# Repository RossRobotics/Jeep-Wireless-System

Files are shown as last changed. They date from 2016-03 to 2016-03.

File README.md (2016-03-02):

# Jeep Wireless System
##Adding Wireless features for exterior lights on a Jeep Wrangler TJ.  All related files will be in this Repository.

#Wireless Features Include:
* Parking lights
* LED Fog Lights
* LED Light Bar
* Rock Lights: These will be WS2812 RGB LED Custom Strips
* LED Reverse Lights

##As of March 1st, PCB version is 0.2 and is posted here.

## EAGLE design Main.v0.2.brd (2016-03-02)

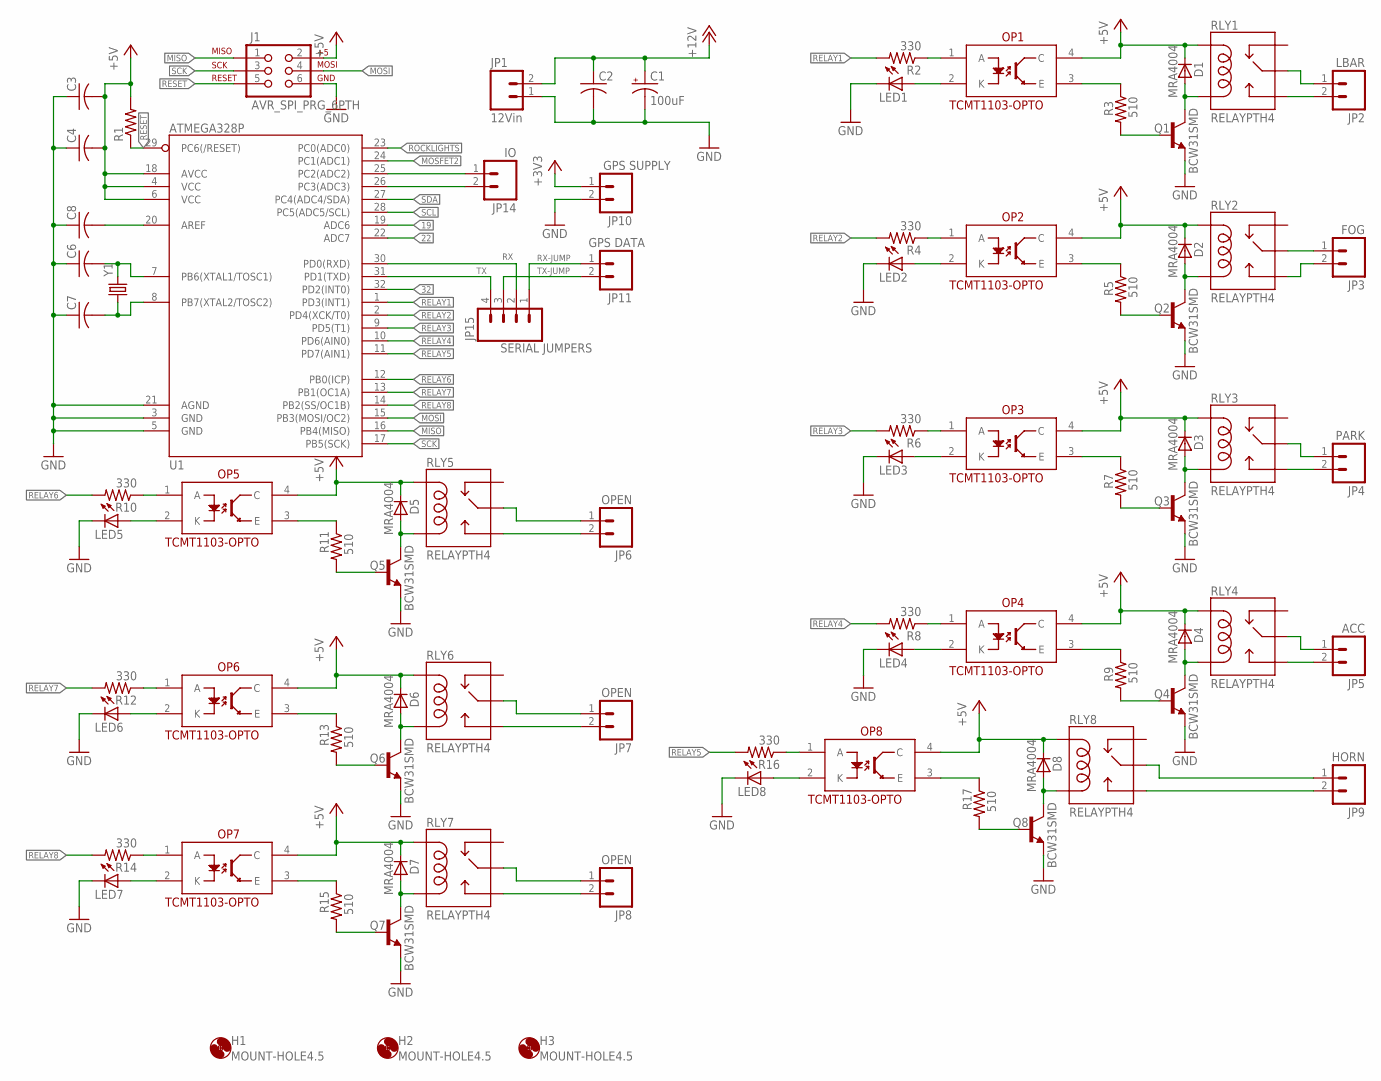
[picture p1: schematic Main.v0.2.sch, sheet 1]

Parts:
C1: 100uF; PANASONIC_F
C2, C3, C4, C6, C7, C8: C-USC1206; C1206
D1, D2, D3, D4, D5, D6, D7, D8: MRA4004; SMA-DIODE_ALT
H1, H2, H3: MOUNT-HOLE4.5; 4,5
J1: AVR_SPI_PRG_6PTH; 2X3
JP1: 12Vin; SCREWTERMINAL-3.5MM-2
JP2: LBAR; SCREWTERMINAL-3.5MM-2
JP3: FOG; SCREWTERMINAL-3.5MM-2
JP4: PARK; SCREWTERMINAL-3.5MM-2
JP5: ACC; SCREWTERMINAL-3.5MM-2
JP6, JP7, JP8: OPEN; SCREWTERMINAL-3.5MM-2
JP9: HORN; SCREWTERMINAL-3.5MM-2
JP10: GPS SUPPLY; SCREWTERMINAL-3.5MM-2
JP11: GPS DATA; SCREWTERMINAL-3.5MM-2
JP14: IO; SCREWTERMINAL-3.5MM-2
JP15: SERIAL JUMPERS; 1X04
LED1, LED2, LED3, LED4, LED5, LED6, LED7, LED8: LED1206; LED-1206
OP1, OP2, OP3, OP4, OP5, OP6, OP7, OP8: TCMT1103-OPTO; SSOP-4
Q1, Q2, Q3, Q4, Q5, Q6, Q7, Q8: BCW31SMD; SOT23-BEC
R1: R-US_R1206; R1206
R2, R4, R6, R8, R10, R12, R14, R16: 330; R1206
R3, R5, R7, R9, R11, R13, R15, R17: 510; R1206
RLY1, RLY2, RLY3, RLY4, RLY5, RLY6, RLY7, RLY8: RELAYPTH4; RELAY-JZC
U1: ATMEGA328P; TQFP32-08
Y1: CRYSTALSMD; HC49UP

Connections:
19: U1.19 (ADC6); also elsewhere on the board
22: U1.22 (ADC7); also elsewhere on the board
32: U1.32 (PD2(INT0)); also elsewhere on the board
+3V3: JP10.1; also elsewhere on the board
+5V: C3.2, C4.2, D1.C, D2.C, D3.C, D4.C, D5.C, D6.C, D7.C, D8.C, J1.2, OP1.4 (C), OP2.4 (C), OP3.4 (C), OP4.4 (C), OP5.4 (C), OP6.4 (C), OP7.4 (C), OP8.4 (C), R1.2, RLY1.5 (COIL1), RLY2.5 (COIL1), RLY3.5 (COIL1), RLY4.5 (COIL1), RLY5.5 (COIL1), RLY6.5 (COIL1), RLY7.5 (COIL1), RLY8.5 (COIL1), U1.4 (VCC), U1.6 (VCC), U1.18 (AVCC); also elsewhere on the board
+12V: C1.+, C2.1, JP1.2; also elsewhere on the board
GND: C1.-, C2.2, C3.1, C4.1, C6.1, C7.1, C8.1, J1.6, JP1.1, JP10.2, LED1.C, LED2.C, LED3.C, LED4.C, LED5.C, LED6.C, LED7.C, LED8.C, Q1.E, Q2.E, Q3.E, Q4.E, Q5.E, Q6.E, Q7.E, Q8.E, U1.3 (GND), U1.5 (GND), U1.21 (AGND); also elsewhere on the board
MISO: J1.1, U1.16 (PB4(MISO))
MOSFET2: U1.24 (PC1(ADC1))
MOSI: J1.4, U1.15 (PB3(MOSI/OC2))
unnamed: LED6.A, OP6.2 (K)
unnamed: D1.A, Q1.C, RLY1.1 (COIL2)
unnamed: C6.2, U1.7 (PB6(XTAL1/TOSC1)), Y1.2
unnamed: C7.2, U1.8 (PB7(XTAL2/TOSC2)), Y1.1
unnamed: C8.2, U1.20 (AREF)
unnamed: Q1.B, R3.2
unnamed: OP1.3 (E), R3.1
unnamed: OP1.1 (A), R2.1
unnamed: LED1.A, OP1.2 (K)
unnamed: D2.A, Q2.C, RLY2.1 (COIL2)
unnamed: Q2.B, R5.2
unnamed: OP2.3 (E), R5.1
unnamed: OP2.1 (A), R4.1
unnamed: LED2.A, OP2.2 (K)
unnamed: D3.A, Q3.C, RLY3.1 (COIL2)
unnamed: Q3.B, R7.2
unnamed: OP3.3 (E), R7.1
unnamed: OP3.1 (A), R6.1
unnamed: LED3.A, OP3.2 (K)
unnamed: D4.A, Q4.C, RLY4.1 (COIL2)
unnamed: Q4.B, R9.2
unnamed: OP4.3 (E), R9.1
unnamed: OP4.1 (A), R8.1
unnamed: LED5.A, OP5.2 (K)
unnamed: D5.A, Q5.C, RLY5.1 (COIL2)
unnamed: Q5.B, R11.2
unnamed: OP5.3 (E), R11.1
unnamed: OP5.1 (A), R10.1
unnamed: LED4.A, OP4.2 (K)
unnamed: D6.A, Q6.C, RLY6.1 (COIL2)
unnamed: Q6.B, R13.2
unnamed: OP6.3 (E), R13.1
unnamed: OP6.1 (A), R12.1
unnamed: LED7.A, OP7.2 (K)
unnamed: D7.A, Q7.C, RLY7.1 (COIL2)
unnamed: Q7.B, R15.2
unnamed: OP7.3 (E), R15.1
unnamed: OP7.1 (A), R14.1
unnamed: LED8.A, OP8.2 (K)
unnamed: D8.A, Q8.C, RLY8.1 (COIL2)
unnamed: Q8.B, R17.2
unnamed: OP8.3 (E), R17.1
unnamed: OP8.1 (A), R16.1
unnamed: JP8.2, RLY7.3 (NO)
unnamed: JP9.2, RLY8.3 (NO)
unnamed: JP8.1, RLY7.4 (MAIN)
unnamed: JP7.1, RLY6.4 (MAIN)
unnamed: JP7.2, RLY6.3 (NO)
unnamed: JP6.2, RLY5.3 (NO)
unnamed: JP6.1, RLY5.4 (MAIN)
unnamed: JP9.1, RLY8.4 (MAIN)
unnamed: JP5.2, RLY4.3 (NO)
unnamed: JP5.1, RLY4.4 (MAIN)
unnamed: JP4.2, RLY3.3 (NO)
unnamed: JP4.1, RLY3.4 (MAIN)
unnamed: JP3.2, RLY2.3 (NO)
unnamed: JP3.1, RLY2.4 (MAIN)
unnamed: JP2.2, RLY1.3 (NO)
unnamed: JP2.1, RLY1.4 (MAIN)
unnamed: JP14.2, U1.26 (PC3(ADC3))
RELAY1: R2.2, U1.1 (PD3(INT1))
RELAY2: R4.2, U1.2 (PD4(XCK/T0))
RELAY3: R6.2, U1.9 (PD5(T1))
RELAY4: R8.2, U1.10 (PD6(AIN0))
RELAY5: R16.2, U1.11 (PD7(AIN1))
RELAY6: R10.2, U1.12 (PB0(ICP))
RELAY7: R12.2, U1.13 (PB1(OC1A))
RELAY8: R14.2, U1.14 (PB2(SS/OC1B))
RESET: J1.5, R1.1, U1.29 (PC6(/RESET))
RFID: JP14.1, U1.25 (PC2(ADC2))
ROCKLIGHTS: U1.23 (PC0(ADC0)); also elsewhere on the board
RX: JP15.2, U1.30 (PD0(RXD)); also elsewhere on the board
RX-JUMP: JP11.1, JP15.1
SCK: J1.3, U1.17 (PB5(SCK))
SCL: U1.28 (PC5(ADC5/SCL)); also elsewhere on the board
SDA: U1.27 (PC4(ADC4/SDA)); also elsewhere on the board
TX: JP15.4, U1.31 (PD1(TXD)); also elsewhere on the board
TX-JUMP: JP11.2, JP15.3

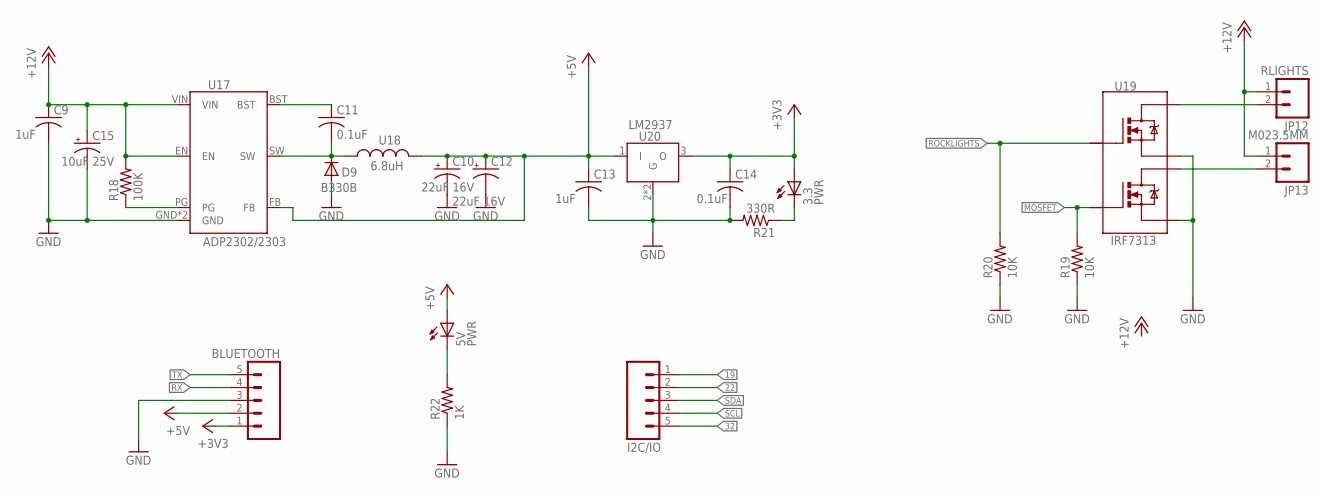
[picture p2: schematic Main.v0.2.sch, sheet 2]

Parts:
3.3, 5V: PWR; LED-1206
BLUETOOTH: M05PTH; 1X05
C9, C13: 1uF; C1206
C10, C12: 22uF 16V; PANASONIC_E
C11, C14: 0.1uF; C1206
C15: 10uF 25V; PANASONIC_E
D9: B330B; DO214AA
I2C/IO: M05PTH; 1X05
JP12: RLIGHTS; SCREWTERMINAL-3.5MM-2
JP13: M023.5MM; SCREWTERMINAL-3.5MM-2
R18: 100K; R1206
R19, R20: 10K; R1206
R21: 330R; R1206
R22: 1K; R1206
U17: ADP2302/2303; 8SOIC
U18: 6.8uH; INDUCTOR
U19: IRF7313; SO-8
U20: LM2937; SOT223

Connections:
19: I2C/IO.1; also elsewhere on the board
22: I2C/IO.2; also elsewhere on the board
32: I2C/IO.5; also elsewhere on the board
+3V3: 3.3.A, BLUETOOTH.1, C14.1, U20.3 (O); also elsewhere on the board
+5V: 5V.A, BLUETOOTH.2, C10.+, C12.+, C13.1, U17.FB, U18.P$2 (2), U20.1 (I); also elsewhere on the board
+12V: C9.1, C15.+, JP12.1, JP13.1, R18.2, U17.EN, U17.VIN; also elsewhere on the board
GND: BLUETOOTH.3, C9.2, C10.-, C12.-, C13.2, C14.2, C15.-, D9.A, R19.1, R20.1, R21.2, R22.1, U17.GND, U17.NC (GND), U19.1 (S), U19.3 (S1), U20.2 (G), U20.4 (G); also elsewhere on the board
MOSFET: R19.2, U19.4 (G1)
unnamed: JP12.2, U19.7 (D), U19.8 (D)
unnamed: JP13.2, U19.5 (D1), U19.6 (D1)
unnamed: R18.1, U17.PG
unnamed: 3.3.C, R21.1
unnamed: C11.1, U17.BST
unnamed: 5V.C, R22.2
ROCKLIGHTS: R20.2, U19.2 (G); also elsewhere on the board
RX: BLUETOOTH.4; also elsewhere on the board
SCL: I2C/IO.4; also elsewhere on the board
SDA: I2C/IO.3; also elsewhere on the board
SW: C11.2, D9.C, U17.SW, U18.P$1 (1)
TX: BLUETOOTH.5; also elsewhere on the board

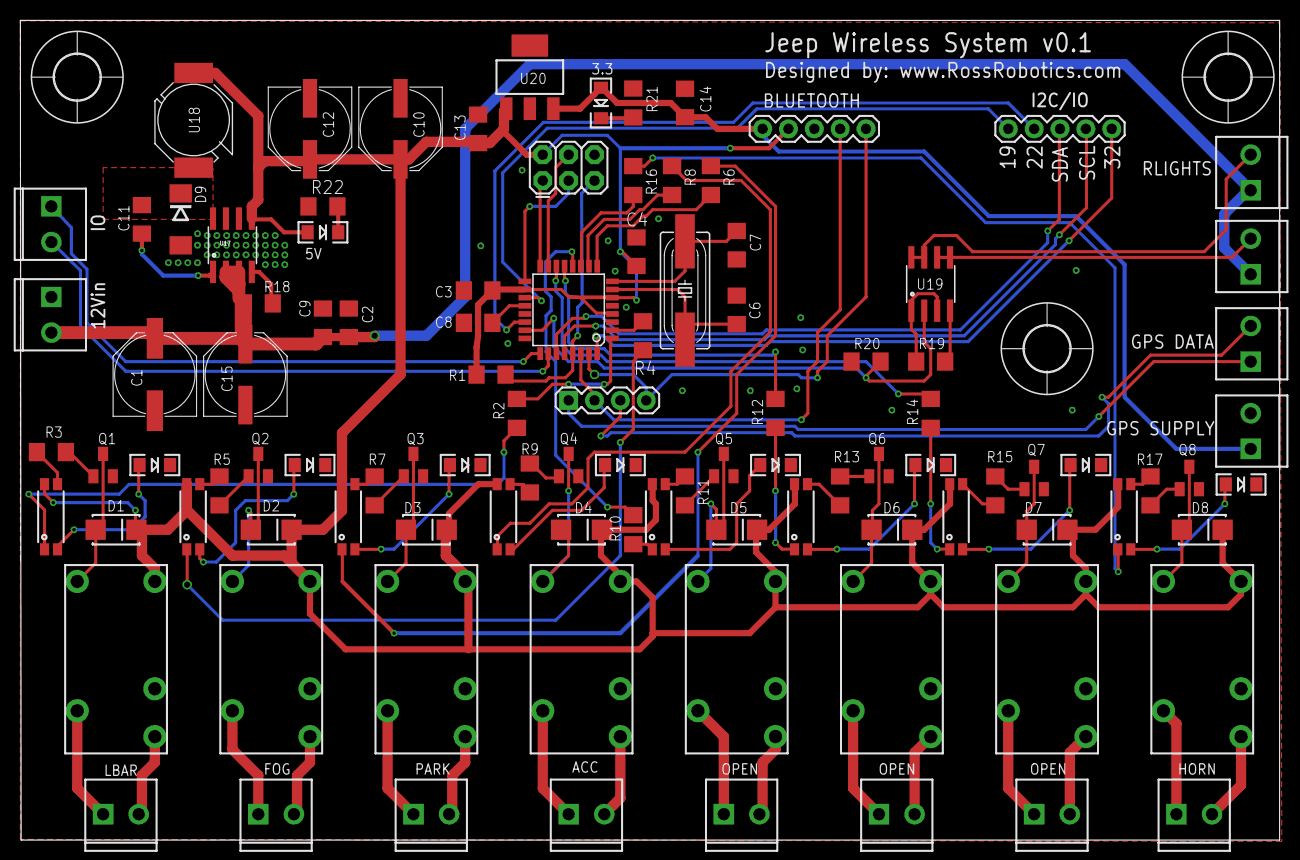
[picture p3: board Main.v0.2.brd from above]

Board: 2 copper layers, 123.7 x 80.5 mm, 106 parts (0 on the bottom side), 95 nets.

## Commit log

2016-03-02 Schematic of main PCB board
    This is version 0.2 of the schematic.
    [Main.v0.2.sch]
2016-03-02 Board layout for the main board
    brd file from Eagle CAD v7.5
    [Main.v0.2.brd]

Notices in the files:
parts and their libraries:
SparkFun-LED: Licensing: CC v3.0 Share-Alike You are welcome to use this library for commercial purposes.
